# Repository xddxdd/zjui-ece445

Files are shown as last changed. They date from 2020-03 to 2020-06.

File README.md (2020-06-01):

Air Quality Sensing Network
===========================

Cloud Server Installation
-------------------------

1. I do not recommend using a cloud server located in mainland China, since then you need to register with the government (备案) to host a website.
   - You may choose servers located in Hong Kong, for example.
2. Install InfluxDB
   - [https://docs.influxdata.com/influxdb/v1.8/introduction/install/](https://docs.influxdata.com/influxdb/v1.8/introduction/install/)
3. Create a database named `air_quality`.
4. Create 3 users:
   - [https://docs.influxdata.com/influxdb/v1.8/administration/authentication_and_authorization/](https://docs.influxdata.com/influxdb/v1.8/administration/authentication_and_authorization/)
   - The first is administrator for InfluxDB server.
   - The second is for sensors to upload data.
     - Username: `***REMOVED***`
     - Password: `***REMOVED***`
   - The third is for website system to read data.
     - Username: `***REMOVED***`
     - Password: `***REMOVED***`
5. Make sure you can access InfluxDB via `[Server IP]:8086`.

STM32 Installation
------------------

1. Modify `stm32/Src/run.h`:
   - Change `HTTP_INFLUXDB_IP` etc to point to your cloud server
   - If you changed username or password for the upload user, also update them here
   - Change `ZJUWLAN_USERNAME` and `ZJUWLAN_PASSWORD` to your own, for auto login to ZJU Wi-Fi
2. Run `make` in `stm32` directory.
   - I'm assuming you use Mac or Linux. I never tried to compile the project on Windows.
   - You need to download GNU Arm Embedded Toolchain.
3. Put the jumper on the top of STM32 (closer to the 4 unsoldered holes) to right, to enter download mode
4. Connect a serial to USB converter:
   - PA9 (GPS module's TX) - Converter's RX
   - PA10 (GPS module's RX) - Converter's TX
   - Ground pin (choose any one) - Converter's GND
5. Run following command to flash program to STM32:
   - `stm32flash /dev/ttyUSB0 -w build/stm32.bin -v -g 0x0`
   - Now the program should start running
6. If you want to put STM32 to field-test, put the jumper on the top of STM32 to left, to enter normal working mode
   - Now STM32 will start running the flashed program once power is on
7. You can use STM32CubeMX to open the `stm32/stm32.ioc` project to change pin definition, regenerate library code, etc.

Web Server Installation
-----------------------

1. Install nginx and PHP on the cloud server:
   - [https://www.digitalocean.com/community/tutorials/how-to-install-linux-nginx-mysql-php-lemp-stack-ubuntu-18-04](https://www.digitalocean.com/community/tutorials/how-to-install-linux-nginx-mysql-php-lemp-stack-ubuntu-18-04)
   - Point website root folder to `webpage` folder.
2. Install Python 3 on the server, and libraries that are needed:
   - `apt install python3 python3-pip python3-numpy python3-matplotlib `
   - `pip3 install influxdb windrose`
3. Enter `python` directory, run `python3 run.py` to refresh website.
   - Remember to update InfluxDB address/user/password in `fetch.py`.
   - Use tools such as Cron or Systemd to run it periodically.
4. Run `python3 weatherlink.py` to crawl wind direction & speed from weather station and upload to InfluxDB.
   - Also remember to update InfluxDB address/user/password in `weatherlink.py`.
   - Use tools such as Supervisord or Systemd to run it continuously.

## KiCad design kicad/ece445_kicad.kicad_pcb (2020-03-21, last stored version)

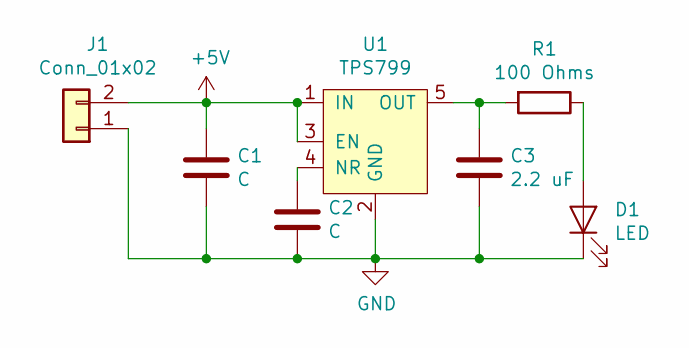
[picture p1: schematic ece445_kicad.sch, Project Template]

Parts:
C1, C2: C; CP_Radial_D5.0mm_P2.50mm
C3: 2.2 uF; CP_Radial_D5.0mm_P2.50mm
D1: LED; LED_Rectangular_W5.0mm_H2.0mm
J1: Conn_01x02; PinHeader_1x02_P2.54mm_Vertical
R1: 100 Ohms; R_Axial_DIN0204_L3.6mm_D1.6mm_P5.08mm_Horizontal
U1: TPS799

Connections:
+5V: C1.1, J1.2, U1.1 (IN), U1.3 (EN)
GND: C1.2, C2.2, C3.2, D1.1 (K), J1.1, U1.2 (GND)
unnamed: C2.1, U1.4 (NR)
unnamed: C3.1, R1.2, U1.5 (OUT)
unnamed: D1.2 (A), R1.1

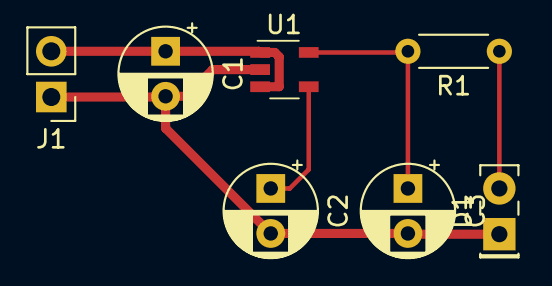
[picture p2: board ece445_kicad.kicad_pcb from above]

Board: 2 copper layers, 7 parts (0 on the bottom side), 5 nets.

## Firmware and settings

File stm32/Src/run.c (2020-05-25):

#include "run.h"
#include "bme680/run_bme680.h"
#include "main.h"
#include <stdio.h>

// Disable uploading calibration & testing
#define TEST_MODE 1

extern ADC_HandleTypeDef hadc1;
extern I2C_HandleTypeDef hi2c1;
extern RTC_HandleTypeDef hrtc;
extern UART_HandleTypeDef huart1;
extern UART_HandleTypeDef huart2;
extern UART_HandleTypeDef huart3;

measure_value_t measure_value;

extern void loop_pms5003();
extern void loop_adc();
extern void loop_esp8266();
extern void GPS_Process(void);
uint32_t id = 10;

void loop_job(uint32_t do_upload);
void loop_print();
void deep_sleep(uint32_t seconds);

void setup() {
    // Virtual release of key of battery module
    HAL_GPIO_WritePin(GPIOB, GPIO_PIN_5, GPIO_PIN_SET);

    if(0 != bme680_my_init()) blink(6);

    // Locate with GPS
    measure_value.gps.latitude[0] = '0';
    measure_value.gps.latitude[1] = '\0';
    measure_value.gps.longitude[0] = '0';
    measure_value.gps.longitude[1] = '\0';

    HAL_GPIO_WritePin(GPIOA, GPIO_PIN_1, GPIO_PIN_RESET);
    HAL_GPIO_WritePin(GPIOB, GPIO_PIN_14, GPIO_PIN_RESET);

    // Continuously run to warm up some sensors,
    // and generate random session ID with measurement uncertainty in process (disabled for now)
    for(int i = 0; i < 5; i++) {
        // Turn on LED & MICS6814 & GPS, and preheat for 30s
        HAL_GPIO_WritePin(GPIOB, GPIO_PIN_12, GPIO_PIN_RESET);
        loop_job(0);
        HAL_GPIO_WritePin(GPIOB, GPIO_PIN_12, GPIO_PIN_SET);

        HAL_Delay(1000);
    }
    // // Turn off MICS6814 & GPS
    // // Not necessary since they will be used immediately afterwards
    // HAL_GPIO_WritePin(GPIOA, GPIO_PIN_1, GPIO_PIN_SET);
    // HAL_GPIO_WritePin(GPIOB, GPIO_PIN_14, GPIO_PIN_SET);
}

void deep_sleep(uint32_t seconds) {
#if 0 == TEST_MODE
    RTC_TimeTypeDef rtc_time = {0, 0, 0};
    RTC_AlarmTypeDef rtc_alarm = {
        {
            seconds / 3600,
            (seconds % 3600) / 60,
            seconds % 60
        },
        RTC_ALARM_A
    };

    HAL_RTC_SetTime(&hrtc, &rtc_time, RTC_FORMAT_BIN);
    HAL_RTC_SetAlarm_IT(&hrtc, &rtc_alarm, RTC_FORMAT_BIN);

    __HAL_PWR_CLEAR_FLAG(PWR_FLAG_WU);
    HAL_PWR_EnterSTOPMode(PWR_LOWPOWERREGULATOR_ON, PWR_STOPENTRY_WFI);

    extern volatile uint32_t uwTick;
    uwTick += seconds * 1000;
#endif
}

void loop() {
    // Turn on LED & MICS6814 & GPS
    HAL_GPIO_WritePin(GPIOA, GPIO_PIN_1, GPIO_PIN_RESET);
    HAL_GPIO_WritePin(GPIOB, GPIO_PIN_12, GPIO_PIN_RESET);
    HAL_GPIO_WritePin(GPIOB, GPIO_PIN_14, GPIO_PIN_RESET);

    // Preheat MICS6814 for 30s, and give GPS 30s for scanning satellites
    #if 0 == TEST_MODE
        // Don't need to toggle battery module every time
        // since MICS6814 & GPS are on and drawing lots of current
        HAL_Delay(30000);
    #endif
    loop_job(1);

    // Turn off LED & MICS6814 & GPS
    HAL_GPIO_WritePin(GPIOA, GPIO_PIN_1, GPIO_PIN_SET);
    HAL_GPIO_WritePin(GPIOB, GPIO_PIN_12, GPIO_PIN_SET);
    HAL_GPIO_WritePin(GPIOB, GPIO_PIN_14, GPIO_PIN_SET);

    // Wait 85 cycles of 10.5s each, total = 892.5s
    #if 0 == TEST_MODE
        for(size_t i = 0; i < 85; i++) {
            // Toggle battery module each time
            deep_sleep(10);
            HAL_GPIO_WritePin(GPIOB, GPIO_PIN_5, GPIO_PIN_RESET);
            HAL_GPIO_WritePin(GPIOB, GPIO_PIN_12, GPIO_PIN_RESET);
            HAL_Delay(500);
            HAL_GPIO_WritePin(GPIOB, GPIO_PIN_5, GPIO_PIN_SET);
            HAL_GPIO_WritePin(GPIOB, GPIO_PIN_12, GPIO_PIN_SET);
        }
    #endif
}

void loop_job(uint32_t do_upload) {
    measure_value.bme680.air_quality = -1;
    measure_value.bme680.co2 = -1;
    measure_value.bme680.humidity = -1;
    measure_value.bme680.pressure = -1;
    measure_value.bme680.temperature = -1;
    measure_value.bme680.tvoc = -1;
    measure_value.mics6814.co = -1;
    measure_value.mics6814.nh3 = -1;
    measure_value.mics6814.no2 = -1;
    measure_value.pms5003.pm1 = -1;
    measure_value.pms5003.pm2_5 = -1;
    measure_value.pms5003.pm10 = -1;
    measure_value.stm32.temp = -1;
    measure_value.stm32.vrefint = -1;
    measure_value.stm32.vbat = -1;

    if(do_upload) {
        #if 0 == TEST_MODE
            GPS_Process();
            HAL_GPIO_WritePin(GPIOB, GPIO_PIN_12, GPIO_PIN_RESET);
        #endif
    }

    loop_pms5003();
    loop_adc();
    bme680_my_loop();

    if(do_upload) {
        loop_print();
        #if 0 == TEST_MODE
            loop_esp8266();
        #endif
    }

    // Turn off LED
    HAL_GPIO_WritePin(GPIOB, GPIO_PIN_12, GPIO_PIN_SET);
}

void loop_print() {
    char tcp_content_buf[TCP_BUF_SIZE];
    uint32_t tcp_content_len;
    tcp_content_len = snprintf(
        tcp_content_buf,
        TCP_BUF_SIZE,

        #if 0 == TEST_MODE
            "pms5003_pm1,id=%lu value=%u\n"
            "pms5003_pm2_5,id=%lu value=%u\n"
            "pms5003_pm10,id=%lu value=%u\n"
            "bme680_tmp,id=%lu value=%f\n"
            "bme680_prs,id=%lu value=%f\n"
            "bme680_hum,id=%lu value=%f\n"
            "bme680_tvoc,id=%lu value=%f\n"
            "bme680_co2,id=%lu value=%f\n"
            "bme680_iaq,id=%lu value=%f\n"
            "mics_co,id=%lu value=%f\n"
            "mics_nh3,id=%lu value=%f\n"
            "mics_no2,id=%lu value=%f\n"
            "stm32_tmp,id=%lu value=%f\n"
            "stm32_vref,id=%lu value=%f\n"
            "stm32_vbat,id=%lu value=%f\n"
            "gps_lat,id=%lu value=%s\n"
            "gps_lon,id=%lu value=%s\n"
        #else
            "pms5003_pm1,id=%lu value=%u\r\n"
            "pms5003_pm2_5,id=%lu value=%u\r\n"
            "pms5003_pm10,id=%lu value=%u\r\n"
            "bme680_tmp,id=%lu value=%f\r\n"
            "bme680_prs,id=%lu value=%f\r\n"
            "bme680_hum,id=%lu value=%f\r\n"
            "bme680_tvoc,id=%lu value=%f\r\n"
            "bme680_co2,id=%lu value=%f\r\n"
            "bme680_iaq,id=%lu value=%f\r\n"
            "mics_co,id=%lu value=%f\r\n"
            "mics_nh3,id=%lu value=%f\r\n"
            "mics_no2,id=%lu value=%f\r\n"
            "stm32_tmp,id=%lu value=%f\r\n"
            "stm32_vref,id=%lu value=%f\r\n"
            "stm32_vbat,id=%lu value=%f\r\n"
            "gps_lat,id=%lu value=%s\r\n"
            "gps_lon,id=%lu value=%s\r\n"
        #endif
        
        ,

        id, measure_value.pms5003.pm1,
        id, measure_value.pms5003.pm2_5,
        id, measure_value.pms5003.pm10,
        id, measure_value.bme680.temperature,
        id, measure_value.bme680.pressure,
        id, measure_value.bme680.humidity,
        id, measure_value.bme680.tvoc,
        id, measure_value.bme680.co2,
        id, measure_value.bme680.air_quality,
        id, measure_value.mics6814.co,
        id, measure_value.mics6814.nh3,
        id, measure_value.mics6814.no2,
        id, measure_value.stm32.temp,
        id, measure_value.stm32.vrefint,
        id, measure_value.stm32.vbat,
        id, measure_value.gps.latitude,
        id, measure_value.gps.longitude
    );
    #if 1 == TEST_MODE
        HAL_UART_Transmit(&huart1, (uint8_t*) tcp_content_buf, tcp_content_len, 1000);
    #endif

    #if 0 == TEST_MODE
    extern char tcp_send_buf[TCP_BUF_SIZE];
    extern uint32_t tcp_send_len;
    const char template[] = 
        "POST /write?u=" HTTP_INFLUXDB_USER "&p=" HTTP_INFLUXDB_PASS "&db=" HTTP_INFLUXDB_DB " HTTP/1.1\r\n"
        "Host: " HTTP_INFLUXDB_IP ":" HTTP_INFLUXDB_PORT "\r\n"
        "User-Agent: zjui-ece/4.4.5\r\n"
        "Content-Type: application/x-www-form-urlencoded\r\n"
        "Connection: close\r\n"
        "Content-Length: %lu\r\n"
        "\r\n"
        "%s"
    ;
    tcp_send_len = snprintf(
        tcp_send_buf,
        TCP_BUF_SIZE,
        template,
        tcp_content_len,
        tcp_content_buf
    );
    #endif
}

void blink(uint32_t times) {
    for(int i = 0; i < times; i++) {
        HAL_GPIO_WritePin(GPIOB, GPIO_PIN_12, GPIO_PIN_RESET);
        HAL_Delay(100);
        HAL_GPIO_WritePin(GPIOB, GPIO_PIN_12, GPIO_PIN_SET);
        HAL_Delay(100);
    }
    HAL_Delay(500);
}

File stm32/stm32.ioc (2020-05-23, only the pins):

Mcu.UserName=STM32F103C8Tx
PA1.GPIO_Label=EN_MICS6814
PA1.Signal=GPIO_Output
PA10.GPIO_Label=USART1_RX_GPS
PA10.Signal=USART1_RX
PA2.GPIO_Label=USART2_TX_PMS5003
PA2.Signal=USART2_TX
PA3.GPIO_Label=USART2_RX_PMS5003
PA3.Signal=USART2_RX
PA4.GPIO_Label=ADC1_IN4_MICS6814_CO
PA4.Signal=ADCx_IN4
PA5.GPIO_Label=ADC1_IN4_MICS6814_NH3
PA5.Signal=ADCx_IN5
PA6.GPIO_Label=ADC1_IN4_MICS6814_NO2
PA6.Signal=ADCx_IN6
PA7.Signal=ADCx_IN7
PA8.GPIO_Label=EN_ESP8266
PA8.Signal=GPIO_Output
PA9.GPIO_Label=USART1_TX_GPS
PA9.Signal=USART1_TX
PB10.GPIO_Label=USART3_TX_ESP8266
PB10.Signal=USART3_TX
PB11.GPIO_Label=USART3_RX_ESP8266
PB11.Signal=USART3_RX
PB12.GPIO_Label=EN_LED
PB12.Signal=GPIO_Output
PB14.GPIO_Label=EN_GPS
PB14.Signal=GPIO_Output
PB15.GPIO_Label=EN_PMS5003
PB15.Signal=GPIO_Output
PB5.GPIO_Label=TOGGLE_BAT
PB5.Signal=GPIO_Output
PB6.GPIO_Label=I2C1_SCL_BME680
PB6.Signal=I2C1_SCL
PB7.GPIO_Label=I2C1_SDA_BME680
PB7.Signal=I2C1_SDA

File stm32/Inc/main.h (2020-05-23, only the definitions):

#define EN_MICS6814_Pin GPIO_PIN_1
#define EN_MICS6814_GPIO_Port GPIOA
#define USART2_TX_PMS5003_Pin GPIO_PIN_2
#define USART2_TX_PMS5003_GPIO_Port GPIOA
#define USART2_RX_PMS5003_Pin GPIO_PIN_3
#define USART2_RX_PMS5003_GPIO_Port GPIOA
#define ADC1_IN4_MICS6814_CO_Pin GPIO_PIN_4
#define ADC1_IN4_MICS6814_CO_GPIO_Port GPIOA
#define ADC1_IN4_MICS6814_NH3_Pin GPIO_PIN_5
#define ADC1_IN4_MICS6814_NH3_GPIO_Port GPIOA
#define ADC1_IN4_MICS6814_NO2_Pin GPIO_PIN_6
#define ADC1_IN4_MICS6814_NO2_GPIO_Port GPIOA
#define USART3_TX_ESP8266_Pin GPIO_PIN_10
#define USART3_TX_ESP8266_GPIO_Port GPIOB
#define USART3_RX_ESP8266_Pin GPIO_PIN_11
#define USART3_RX_ESP8266_GPIO_Port GPIOB
#define EN_LED_Pin GPIO_PIN_12
#define EN_LED_GPIO_Port GPIOB
#define EN_GPS_Pin GPIO_PIN_14
#define EN_GPS_GPIO_Port GPIOB
#define EN_PMS5003_Pin GPIO_PIN_15
#define EN_PMS5003_GPIO_Port GPIOB
#define EN_ESP8266_Pin GPIO_PIN_8
#define EN_ESP8266_GPIO_Port GPIOA
#define USART1_TX_GPS_Pin GPIO_PIN_9
#define USART1_TX_GPS_GPIO_Port GPIOA
#define USART1_RX_GPS_Pin GPIO_PIN_10
#define USART1_RX_GPS_GPIO_Port GPIOA
#define TOGGLE_BAT_Pin GPIO_PIN_5
#define TOGGLE_BAT_GPIO_Port GPIOB
#define I2C1_SCL_BME680_Pin GPIO_PIN_6
#define I2C1_SCL_BME680_GPIO_Port GPIOB
#define I2C1_SDA_BME680_Pin GPIO_PIN_7
#define I2C1_SDA_BME680_GPIO_Port GPIOB

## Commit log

2020-03-21 PCB assignment
    [ece445_kicad-B_Cu.gbr, ece445_kicad-B_Mask.gbr, ece445_kicad-B_Paste.gbr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]
2020-03-31 stm32: blinker working
2020-03-31 stm32: i2c work in progress
2020-03-31 stm32: bme680 almost working
2020-03-31 stm32: bme680 fully working
2020-03-31 stm32: remove build files from repo
2020-03-31 stm32: general coding style fixes
    [run.c, run_bme680.c]
2020-03-31 stm32: code simplification
2020-03-31 stm32: adc works
2020-04-17 stm32: pms5003 working
2020-04-17 stm32: general cleanup
2020-04-17 stm32: stop mode and rtc wakeup
2020-04-21 stm32: update mics6814 formula
2020-04-21 stm32: add IAQ calculation
2020-04-21 stm32: use BSEC for BME680 (still dont work)
2020-04-21 stm32: bme680 bsec work, switch to printf
2020-04-21 stm32: code cleanup
2020-04-24 stm32: send results over TCP
2020-04-25 stm32: reduce code size
2020-04-25 stm32: further shrink binary size
2020-04-25 stm32: fix mics6814 formula
    [adc.c]
2020-04-25 stm32: upload to influxdb, pseudo rng for session id
2020-04-26 stm32: try to fix mics6814 (but failed)
    [adc.c, esp8266.c, run.c]
2020-04-26 stm32: esp8266 powersave optimization
2020-05-01 stm32: add experimental gps
2020-05-01 stm32: shrink code size in progress
2020-05-01 stm32: use LL driver for RCC to shrink binary size
2020-05-01 stm32: blink when waiting for gps
2020-05-01 stm32: add gps debugging
2020-05-01 stm32: remove unneeded library files
2020-05-01 stm32: update project
2020-05-02 stm32: confirm gps works
2020-05-05 stm32: add pin definition (unused for now)
2020-05-06 stm32: adopt for ZJUWLAN network
2020-05-14 stm32: add mosfet control & vbat measurement & conversion
2020-05-22 stm32: multiple changes
2020-05-22 stm32: influxdb bugfix
2020-05-22 stm32: gps reporting bugfix
    [GPS.c]
2020-05-23 stm32: trigger battery module periodically, further reduce frequency
2020-05-25 windrose map added
    [data.xlsx]
2020-05-25 webpage & stm32: update
2020-05-26 add battery plot script
2020-06-01 general: cleanup before handover project
    [data.xlsx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]

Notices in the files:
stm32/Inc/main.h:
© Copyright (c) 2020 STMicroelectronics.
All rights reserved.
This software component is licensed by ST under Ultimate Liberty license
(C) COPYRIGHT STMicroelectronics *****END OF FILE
